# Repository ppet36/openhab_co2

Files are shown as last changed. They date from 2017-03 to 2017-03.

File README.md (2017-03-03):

# OpenHAB CO2 sensor

This repository contains Cadsoft's Eagle schematic and PCBs as well as Arduino firmware for CO2 monitoring device based on ESP8266-01 and relatively cheap CO2 sensor MH-Z19. Device is designed to be powered from USB charger.

## Schematic & PCB

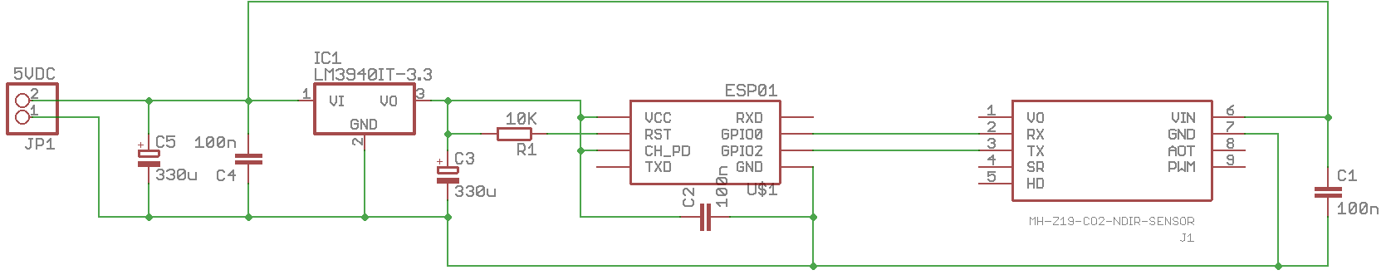
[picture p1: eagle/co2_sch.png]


On schematic is nothing special. Two available pins of ESP01 module is used for serial communication with sensor at 9600 baud rate.

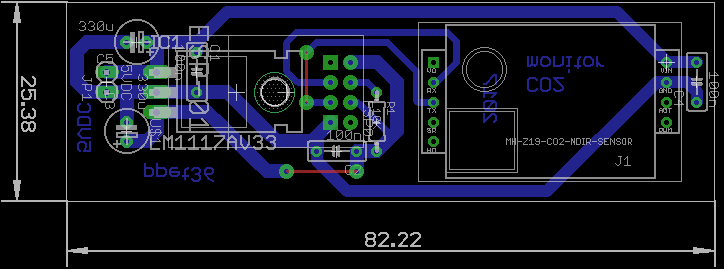
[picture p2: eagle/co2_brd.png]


Board is designed as single-sided with some wire jumpers.

## Firmware

Firmware can be programmed via Arduino IDE. After device startup MH-Z19 sensor returns different values before it is heated up. Firmware first waits for sequence of 400PPM readings and after that for value different than 400PPM; then is sensor heated up and ready for measuring.

WIFI access point and network parameters can be set in source code. After device startup and sensor heated up is on his IP address available HTTP server, which provides measured CO2 PPM value as REST service. Via HTTP server is also available simple configuration page where some parameters can be changed.

Sensor is very sensitive so firmware averages 50 values (by default) for eliminate jitter. Number of averaged values, frequency of reading values from sensor and other parameters can be set in source file or via WEB configuration page. Configuration page is written in very primitive HTML so can be accessed for example from terminal browser; for example "links":

```
links http://192.168.128.209/
```
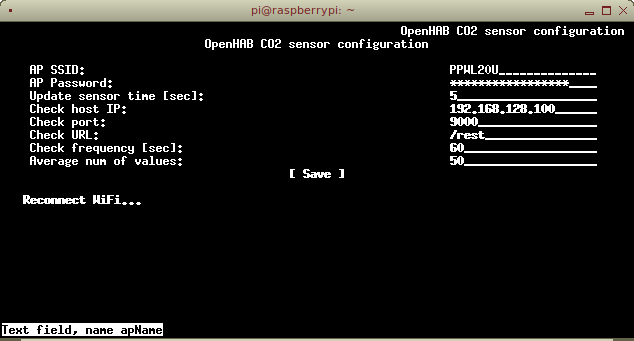
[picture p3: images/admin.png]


## OpenHAB

Configuration in OpenHAB is very simple. First you need to define item (in your *.items file) with correct IP address of device.
```
Number co2PPM "Indoor CO2 [%s PPM]" <co2> { http="<[http://192.168.128.209/co2:15000:JS(intvalue.js)]" } 
```
After item definition is ready, OpenHAB reads every 15 seconds CO2 value from device. To display measured value you need modify your sitemap file. It's also very easy.
```
Text item=co2PPM
```
After successfull definition OpenHAB GUI shows simple text item:



## Case
In openscad directory can be found simple case for whole device. There is OpenSCAD source file as well as rendered STL model.

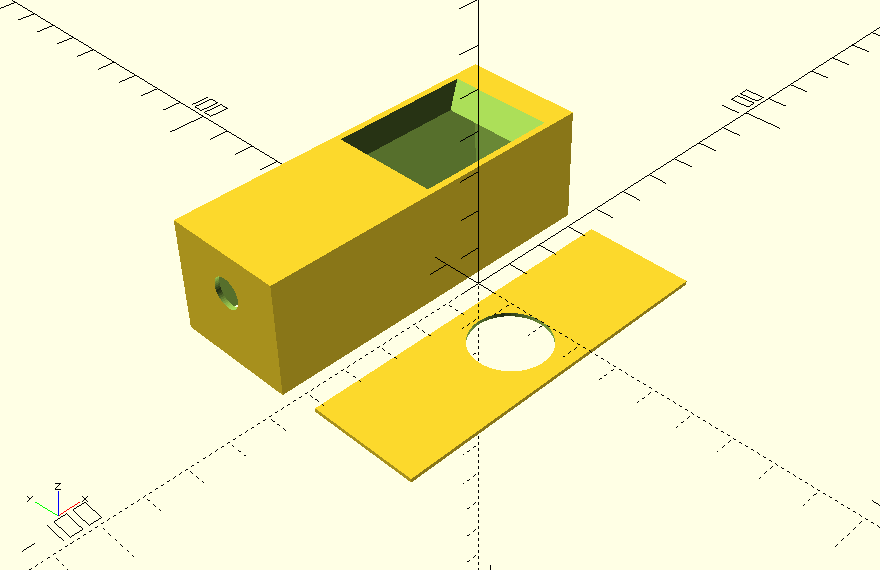
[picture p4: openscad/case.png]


## Some images
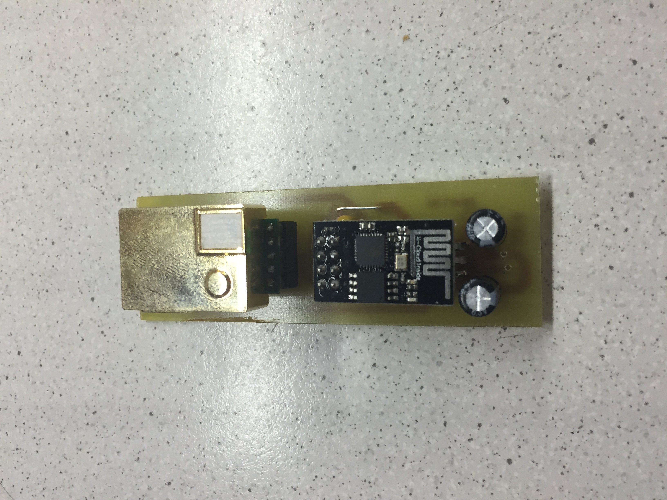
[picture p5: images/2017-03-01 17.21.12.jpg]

Print is not perfect because my printer bed is too dirty. But this is not problem; device will be on cabinet.
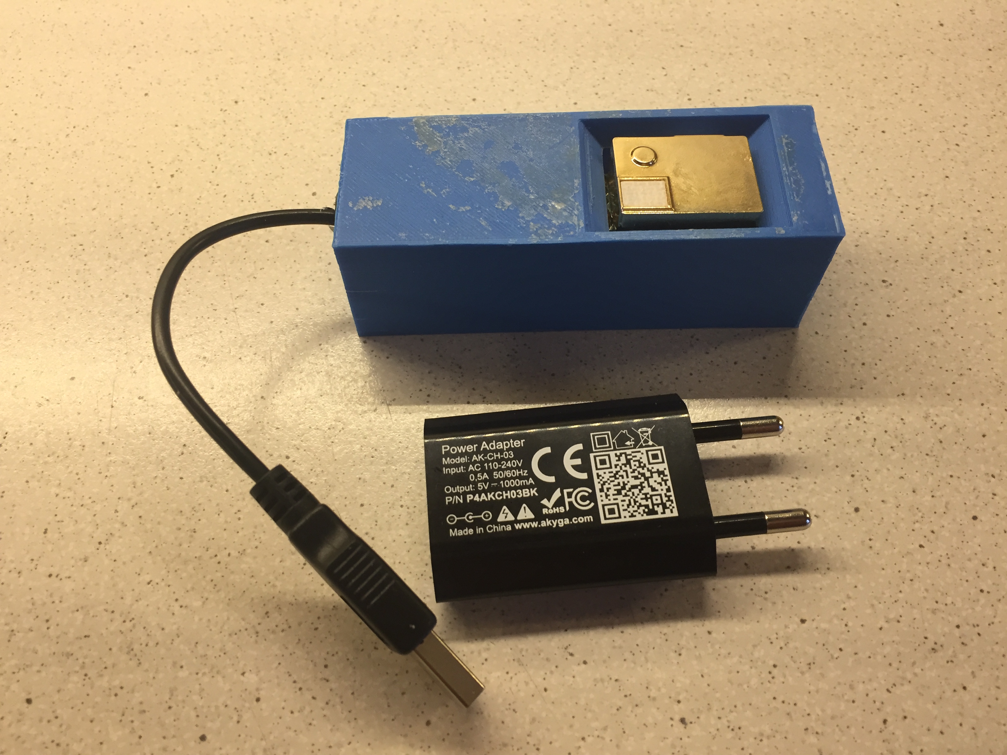
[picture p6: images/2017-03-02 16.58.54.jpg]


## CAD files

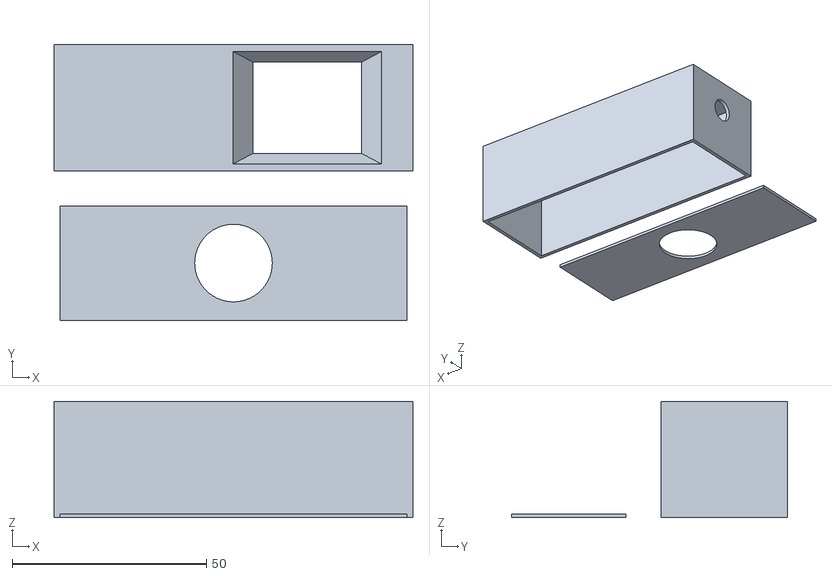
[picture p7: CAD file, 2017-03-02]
openscad/openhab_co2.stl
92.5 x 71.0 x 30.0

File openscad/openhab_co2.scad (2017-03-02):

$fn=50;

module inner() {
  union() {
    cube ([90,30,25], center=true);
    
    translate([6+26/2,0,25/2])
    hull() {
      cube ([27,23,1], center=true);
      translate([0,0,8]) cube ([27+15,23+8,1], center=true);
    }
    
    translate([-50,0,7]) rotate([0,90,0]) cylinder (d=8, h=100, center=true);
  }
}

module box() {
  difference() {
    translate([0,0,3]) cube ([90+2.5,30+2.5,25+5], center=true);
    inner();
    translate([-22.5,0,14]) cube ([45,30,5], center=true);
  }
}

module cap() {
  translate([0,0,-11.5])
  difference() {
    cube ([89.5,29.5,1], center=true);
    cylinder (d=20, h=2, center=true);
  }
}

translate([0,30,0]) box();
translate([0,-10,0]) cap();

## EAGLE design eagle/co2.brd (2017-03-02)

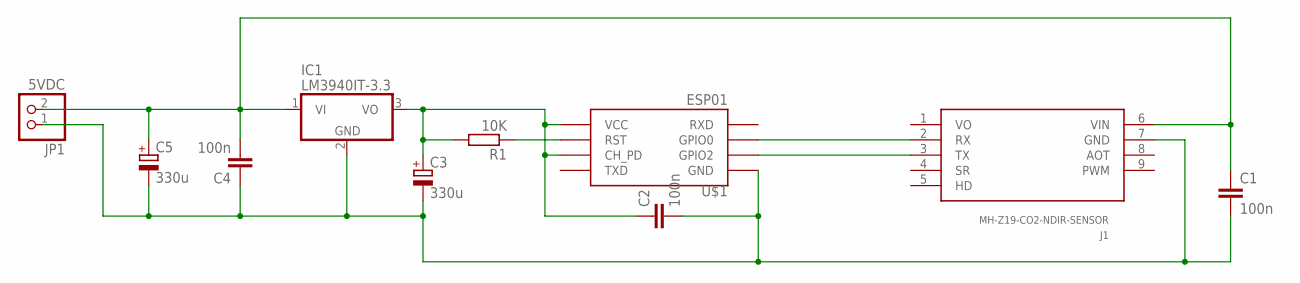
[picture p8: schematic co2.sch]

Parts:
C1, C2, C4: 100n; C050-025X075
C3, C5: 330u; E2,5-6
IC1: LM3940IT-3.3; TO220H
J1: MH-Z19-CO2-NDIR-SENSOR; MH-Z19
JP1: 5VDC; 1X02
R1: 10K; 0204/7
U$1: ESP01

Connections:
+3.3V: C2.1, C3.+, IC1.3 (VO), R1.2, U$1.CH_PD, U$1.VCC
+5V: C1.1, C4.2, C5.+, IC1.1 (VI), J1.6 (VIN), JP1.2
GND: C1.2, C2.2, C3.-, C4.1, C5.-, IC1.2 (GND), J1.7 (GND), JP1.1, U$1.GND
unnamed: J1.2 (RX), U$1.GPIO0
unnamed: J1.3 (TX), U$1.GPIO2
unnamed: R1.1, U$1.RST
VO: J1.1 (VO)

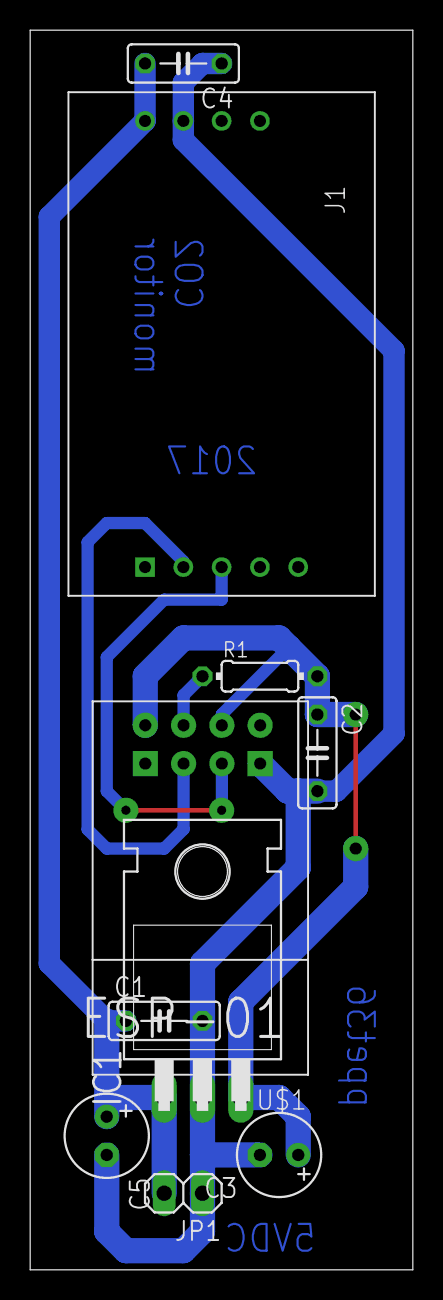
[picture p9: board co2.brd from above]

Board: 2 copper layers, 25.4 x 82.2 mm, 10 parts (0 on the bottom side), 6 nets.

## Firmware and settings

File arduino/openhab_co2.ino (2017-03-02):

/**
 * Simple OpenHAB CO2 sensor based on ESP8266-01 and MH-Z19 CO2 sensor.
*/
#include <EEPROM.h>
#include <ESP8266WiFi.h>
#include <ESP8266HTTPClient.h>
#include <WiFiClient.h>
#include <ESP8266WebServer.h>
#include <SoftwareSerial.h>

// RX/TX for MH-Z19 sensor.
#define MHZ_TX 0  // MH_Z19 RX PIN
#define MHZ_RX 2  // MH_Z19 TX PIN

// Check URL for WIFI
#define DEFAULT_CHECK_HOST "192.168.128.100"
#define DEFAULT_CHECK_PORT 9000
#define DEFAULT_CHECK_URL  "/rest"

// Default frequency of updating CO2 value from sensor (in seconds)
#define DEFAULT_UPDATE_FREQUENCY 5

// Default frequency of check whether WiFi is alive (in seconds)
#define DEFAULT_CHECK_FREQUENCY 60

// Default number of values to average
#define DEFAULT_NUM_OF_VALUES_AVG 50

// Local network definition; must have static IP address
#define LOCAL_IP IPAddress (192, 168, 128, 209)
#define GATEWAY IPAddress (192, 168, 128, 1)
#define SUBNETMASK IPAddress (255, 255, 255, 0)

// Local Wifi AP for connect
#define DEFAULT_WIFI_AP "******"
#define DEFAULT_WIFI_PASSWORD "*********"

// Error count for reconnect WIFI
#define ERR_COUNT_FOR_RECONNECT 30
#define HTTP_READ_TIMEOUT       10000
#define HTTP_CONNECT_TIMEOUT    5000

// Local WEB server port
#define WEB_SERVER_PORT 80

// Magic for detecting empty (unconfigured) EEPROM
#define MAGIC 0xCB

/**
 * EEPROM structure.
*/
struct OhConfiguration {
  int magic;
  char apName [24];
  char password [48];
  char checkHost [20];
  unsigned int checkPort;
  char checkUrl [50];
  unsigned int checkFrequency;
  unsigned int updateFrequency;
  unsigned int averageCount;
};

// Configuration
OhConfiguration config;

// Configuration server
ESP8266WebServer *server = (ESP8266WebServer *) NULL;

// Last interaction time
long lastInteractionTime;

// Last check time
long lastCheckTime;

// Number of communication errors
int errorCount = 0;

// Last CO2 value
int lastCo2Ppm = -1;

// Serial at 9600 baud for communication with MH-Z19
SoftwareSerial co2Serial (MHZ_RX, MHZ_TX);

// Average index
byte averageIndex;

// Average count
byte averageCount;

// Average array
int *averageValues = (int *) NULL;


/**
 * Setup method.
*/
void setup() {
  Serial.begin (115200);
  Serial.println ("setup()");

  co2Serial.begin (9600);

  // Do not operate with WiFi in initialization phase
  WiFi.disconnect();

  // Read config from EEPROM
  EEPROM.begin (sizeof (OhConfiguration));
  EEPROM.get (0, config);
  if (config.magic != MAGIC) {
    memset (&config, 0, sizeof (OhConfiguration));
    config.magic = MAGIC;
    updateConfigKey (config.apName, 24, String(DEFAULT_WIFI_AP));
    updateConfigKey (config.password, 48, String(DEFAULT_WIFI_PASSWORD));
    config.updateFrequency = DEFAULT_UPDATE_FREQUENCY;
    updateConfigKey (config.checkHost, 20, String (DEFAULT_CHECK_HOST));
    config.checkPort = DEFAULT_CHECK_PORT;
    updateConfigKey (config.checkUrl, 50, String(DEFAULT_CHECK_URL));
    config.checkFrequency = DEFAULT_CHECK_FREQUENCY;
    config.averageCount = DEFAULT_NUM_OF_VALUES_AVG;
  }

  // Init average array
  averageValues = (int *) calloc (config.averageCount, sizeof(int));
  averageIndex = 0;
  averageCount = 0;

  delay (5000);

  // Warm sensor
  warmSensor();

  // Fill average values
  fillAverageValues();

  // Connect to WiFi and create HTTP server
  reconnectWifi();
  createServer();

  lastInteractionTime = millis();
  lastCheckTime = lastInteractionTime;
}

/**
 * Prints HEX array; for debug purposes.
 * 
 * @param data data.
 * @param length length;
*/
void printHex8 (uint8_t *data, uint8_t length) {
  char tmp [length*2 + 1];
  byte first;
  byte second;
  for (int i = 0; i < length; i++) {
    first = (data[i] >> 4) & 0x0f;
    second = data[i] & 0x0f;
    tmp [i*2] = first + 48;
    tmp [i*2 + 1] = second + 48;
    if (first > 9) {
      tmp [i*2] += 39;
    }

    if (second > 9) {
      tmp [i*2 + 1] += 39;
    }
  }
  tmp [length*2] = 0;
  Serial.print (tmp);
}

/**
 * Reads CO2 sensor and returns CO2 PPM.
 * 
 * @return int CO2 PPM value or -1 on error.
*/
int readCO2() {
  // cleanup input
  while (co2Serial.available()) co2Serial.read();
  
  // command to get PPM value
  byte cmd[9] = {0xFF, 0x01, 0x86, 0x00, 0x00, 0x00, 0x00, 0x00, 0x79};

  byte response[9];

  Serial.print ("Sensor request: ");
  printHex8 (cmd, 9);
  Serial.println();
  
  // write command and read response
  co2Serial.write (cmd, 9);
  co2Serial.readBytes (response, 9);

  Serial.print ("Sensor response: ");
  printHex8 (response, 9);
  Serial.println();
  
  // basic check of response
  if ((response[0] != 0xFF) || (response[1] != 0x86)) {
    Serial.println ("Failed to read from CO2 sensor!");
    return -1;
  }

  // calculate and check checksum
  char i, checksum = 0;
  for (i = 1; i < 8; i++) {
    checksum += response [i];
  }
  checksum = 0xff - checksum;
  checksum += 1;

  if (checksum != response [8]) {
    Serial.print ("Invalid checksum "); Serial.print (checksum); Serial.print (" <> "); Serial.print (response [8]); Serial.println ("!");
    return -1;
  }

  // calculate PPM value
  int responseHigh = (int) response[2];
  int responseLow = (int) response[3];
  int ppm = (256 * responseHigh) + responseLow;

  Serial.print ("CO2 PPM: "); Serial.println (ppm);

  return ppm;
}

/**
 * Adds new measure to average values.
*/
void updateCo2Ppm() {
  int val = readCO2();

  // ocassionaly sensor returns 5000, this value can be quietly ignored
  if ((val == 5000) || (val < 0)) {
    return;
  }

  averageValues [averageIndex++] = val;
  if (averageIndex >= config.averageCount) {
    averageIndex = 0;
  }

  averageCount++;
  if (averageCount > config.averageCount) {
    averageCount = config.averageCount;
  }
}

/**
 * Returns average value of CO2 PPM.
 * 
 * @return int average value.
*/
int readCo2Avg() {
  unsigned long sum = 0L;
  int i;
  for (i = 0; i < averageCount; i++) {
    sum += averageValues [i];
  }
  return sum / averageCount;
}


/**
 * Wait for sensor to warmed. Initialization takes almost one minute, after power on.
*/
void warmSensor() {
  Serial.println ("Waiting for sensor init...");
  delay (500);
  Serial.println ("Waiting for PPM=400...");
  while (true) {
    int rv = readCO2();
    if (rv == 400) {
      break;
    }
    delay (2000);
  }

  delay (1000);
  Serial.println ("Waiting for PPM <> 400...");
  while (true) {
    int rv = readCO2();
    if (rv != 400) {
      break;
    }
    
    delay (2000);
  }

  Serial.println ("Done...");
}

/**
 * Initializes average values. Fills all averageValues.
*/
void fillAverageValues() {
  Serial.println ("Initializing average values...");
  int i;
  for (i = 0; i < config.averageCount; i++) {
    averageValues [i] = readCO2();
    delay (config.updateFrequency * 1000L);
  }
  averageIndex = 0;
  averageCount = config.averageCount;
}


/**
 * Helper routine; updates config key.
 *
 * @param c key.
 * @param len max length.
 * @param val value.
*/
void updateConfigKey (char *c, int len, String val) {
  memset (c, 0, len);
  sprintf (c, "%s", val.c_str());
}

/**
 * Reconects WIFI.
*/
void reconnectWifi() {
  Serial.println ("WiFi disconnected...");
  WiFi.disconnect();
  String hostname = String("openhab_co2 sensor");
  WiFi.hostname (hostname);
  WiFi.config (LOCAL_IP, GATEWAY, SUBNETMASK);
  WiFi.mode (WIFI_STA);
  delay (1000);

  Serial.print ("Connecting to "); Serial.print (config.apName); Serial.print (' ');
  WiFi.begin (config.apName, config.password);
  delay (1000);
  while (WiFi.status() != WL_CONNECTED) {
    yield();
    delay (500);
    Serial.print (".");
  }
  delay (500);
  Serial.println();
  Serial.println ("WiFi connected...");
}

/**
 * Creates HTTP server.
*/
void createServer() {
  if (server) {
    server->close();
    delete server;
    server = NULL;
  }
  
  // ... and run HTTP server for setup
  server = new ESP8266WebServer (LOCAL_IP, WEB_SERVER_PORT);
  server->on ("/co2", wsGetCo2);
  server->on ("/", wsConfig);
  server->on ("/update", wsUpdate);
  server->on ("/reconnect", wsReconnect);
  server->begin();

  Serial.println ("Created server...");
}

/**
 * WS GETs CO2 PPM.
*/
void wsGetCo2() {
  int avg = readCo2Avg();
  Serial.print ("wsGetCo2() -> "); Serial.println (avg);
  server->send (200, "text/html", String(avg));
}

/**
 * Configuration page.
*/
void wsConfig() {
  yield();

  String resp = "<html><head><title>OpenHAB CO2 sensor configuration</title>";
  resp += "<meta name=\"viewport\" content=\"initial-scale=1.0, width = device-width, user-scalable = no\">";
  resp += "</head><body>";
  resp += "<h1>OpenHAB CO2 sensor configuration</h1>";
  resp += "<form method=\"post\" action=\"/update\" id=\"form\">";
  resp += "<table border=\"0\" cellspacing=\"0\" cellpadding=\"5\">";
  resp += "<tr><td>AP SSID:</td><td><input type=\"text\" name=\"apName\" value=\"" + String(config.apName) + "\" maxlength=\"24\"></td><td></td></tr>";
  resp += "<tr><td>AP Password:</td><td><input type=\"password\" name=\"password\" value=\"" + String(config.password) + "\" maxlength=\"48\"></td><td></td></tr>";
  resp += "<tr><td>Update sensor time [sec]:</td><td><input type=\"text\" name=\"updateFrequency\" value=\"" + String(config.updateFrequency) + "\"></td><td></td></tr>";
  resp += "<tr><td>Check host IP:</td><td><input type=\"text\" name=\"checkHost\" value=\"" + String(config.checkHost) + "\" maxlength=\"20\"></td><td></td></tr>";
  resp += "<tr><td>Check port:</td><td><input type=\"text\" name=\"checkPort\" value=\"" + String(config.checkPort) + "\" maxlength=\"5\"></td><td></td></tr>";
  resp += "<tr><td>Check URL:</td><td><input type=\"text\" name=\"checkUrl\" value=\"" + String(config.checkUrl) + "\" maxlength=\"50\"></td><td></td></tr>";
  resp += "<tr><td>Check frequency [sec]:</td><td><input type=\"text\" name=\"checkFrequency\" value=\"" + String(config.checkFrequency) + "\"></td><td></td></tr>";
  resp += "<tr><td>Average num of values:</td><td><input type=\"text\" name=\"averageCount\" value=\"" + String(config.averageCount) + "\"></td><td></td></tr>";

  resp += "<tr><td colspan=\"3\" align=\"center\"><input type=\"submit\" value=\"Save\"></td></tr>";
  resp += "</table></form>";
  resp += "<p><a href=\"/reconnect\">Reconnect WiFi...</a></p>";
  resp += "</body></html>";

  server->send (200, "text/html", resp);
}

/**
 * Reconnects WiFi with new parameters.
*/
void wsReconnect() {
  yield();
  String resp = "<script>window.alert ('Reconnecting WiFi...'); window.location.replace ('/');</script>";
  server->send (200, "text/html", resp);
  reconnectWifi();
  createServer();
}

/**
 * Saves configuration.
*/
void wsUpdate() {
  yield();

  String apName = server->arg ("apName");
  String password = server->arg ("password");
  unsigned int updateFrequency = atoi (server->arg ("updateFrequency").c_str());
  String checkHost = server->arg ("checkHost");
  unsigned int checkPort = atoi (server->arg ("checkPort").c_str());
  String checkUrl = server->arg ("checkUrl");
  unsigned int checkFrequency = atoi (server->arg("checkFrequency").c_str());
  int averageCount = atoi (server->arg("averageCount").c_str());
  
  if (apName.length() > 1) {
    updateConfigKey (config.apName, 24, apName);
    updateConfigKey (config.password, 48, password);
    config.updateFrequency = constrain (updateFrequency, 1, 600);
    updateConfigKey (config.checkHost, 20, checkHost);
    config.checkPort = constrain (checkPort, 1, 65535);
    updateConfigKey (config.checkUrl, 50, checkUrl);
    config.checkFrequency = constrain (checkFrequency, 0, 30000);
    config.averageCount = constrain (averageCount, 1, 120);

    // init average array
    free (averageValues);
    averageValues = (int *) calloc (config.averageCount, sizeof(int));
    averageValues [0] = readCO2();
    averageIndex = 1;
    averageCount = 1;
  
    // store configuration
    EEPROM.begin (sizeof (OhConfiguration));
    EEPROM.put (0, config);
    EEPROM.end();
  
    String resp = "<script>window.alert ('Configuration updated...'); window.location.replace ('/');</script>";
    server->send (200, "text/html", resp);
  } else {
    server->send (200, "text/html", "");
  }
}

/**
 * Checks WIFI connection by getting check URL.
*/
void checkWiFi() {
  if ((strlen (config.checkHost) < 1) || (config.checkFrequency < 1)) {
    return;
  }

  WiFiClient client;

  // connect to OpenHAB
  Serial.print ("Connecting to http://"); Serial.print (config.checkHost); Serial.print (':'); Serial.print (config.checkPort); Serial.print (config.checkUrl); Serial.println (" ...");
  if (client.connect (config.checkHost, config.checkPort)) {
    // send request
    String req = String("GET ") + config.checkUrl + String (" HTTP/1.1\r\n")
      + String("Host: ") + String (config.checkHost) + String ("\r\nConnection: close\r\n\r\n");
    client.print (req);
    Serial.print (req);

    bool isError = false;
    
    // wait HTTP_CONNECT_TIMEOUT for response
    unsigned long connectStartTime = millis();
    while (client.available() == 0) {
      if (millis() - connectStartTime > HTTP_CONNECT_TIMEOUT) {
        errorCount++;
        isError = true;
        break;
      }

      yield();
    }

    Serial.print ("Reading response -> ");
    if (!isError) {
      // read response lines
      unsigned long readStartTime = millis();

      int ch;
      while ((ch = client.read()) != -1) {
        if (millis() - readStartTime > HTTP_READ_TIMEOUT) {
          errorCount++;
          isError = true;
          break;
        }

        yield();
      }

      Serial.println ("OK");
      
      client.stop();
    } else {
      Serial.println ("ERROR");
      client.stop();
    }
  }
}

/**
 * Loop.
*/
void loop() {
  if (server) {
    server->handleClient();
  }
  
  if (millis() - lastInteractionTime > config.updateFrequency * 1000L) {
    yield();

    updateCo2Ppm();

    lastInteractionTime = millis();
  }

  if (millis() - lastCheckTime > config.checkFrequency * 1000L) {
    yield();
    
    if (WiFi.status() == WL_CONNECTED) {
      checkWiFi();
    } else {
      Serial.println ("Wifi not connected!");
      errorCount++;
    }

    // when error count reaches ERR_COUNT_FOR_RECONNECT, reconnect WiFi.
    if (errorCount > ERR_COUNT_FOR_RECONNECT) {
      errorCount = 0;
      reconnectWifi();
      createServer();
    }

    lastCheckTime = millis();
  }

  yield();
}
